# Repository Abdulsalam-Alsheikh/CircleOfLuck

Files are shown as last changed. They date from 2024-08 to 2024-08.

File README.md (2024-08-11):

# Random Number Selector with 12 Segments

This project is an electronic circuit that randomly selects a winner from 12 participants by lighting up the corresponding segment on a circular board. The circuit is built using an Arduino Nano, shift registers, MOSFET transistors, and other components. The design includes a PCB layout, simulation in Proteus, and Arduino code for the logic control.

## Components

- **Arduino Nano**: Controls the entire circuit.
- **2 x 74HC595 Shift Registers**: Expands the number of outputs to control the 12 segments.
- **12 x IRLZ44N MOSFET Transistors**: Used to switch the LEDs for each segment.
- **Resistors**: Various values to limit current and ensure proper operation of the circuit.
- **Power Supply Jack**: To feed the circuit with the required voltage.
- **Junction Connectors**: For connecting each segment to its corresponding transistor.

## Project Files

- **Proteus Simulation File**: A simulation of the circuit to test the functionality before actual implementation **note**( The Arduino code will not work directly here on the simulation due to the adopted method of generating the random number you must change the method of generating the random number before the simulation ) .
- **Arduino Code**: The code used to control the selection process and light up the segments.
- **PCB Design**: A layout of the PCB ready for manufacturing, including all the components and connections.

## Circuit Design

The circuit is designed to randomly select a number from 1 to 12 using an LED on a circular board. The selection is controlled by an Arduino Nano, which sends signals to the shift registers. The shift registers then control the MOSFET transistors, which switch the LEDs on and off based on the random selection.

### How It Works

1. The Arduino generates a random number between 1 and 12.
2. The shift registers receive the number and activate the corresponding MOSFET.
3. The MOSFET then allows current to pass through and lights up the LED corresponding to the selected number.
4. The number remains lit until the process is repeated.

## Usage

1. Load the provided Arduino code into the Arduino Nano.
2. Connect the circuit components as per the schematic in the Proteus file or PCB design.
3. Power the circuit through the power supply jack.
4. The circuit will randomly select a number and light up the corresponding segment.

Watch the final circuit project here [Circuit of CircleOfLuck](https://youtu.be/4vKIFw7FxGo) .
Watch how the circuit logic works here [Logic of CircleOfLuck](https://youtu.be/dwda4XJ68b8) .



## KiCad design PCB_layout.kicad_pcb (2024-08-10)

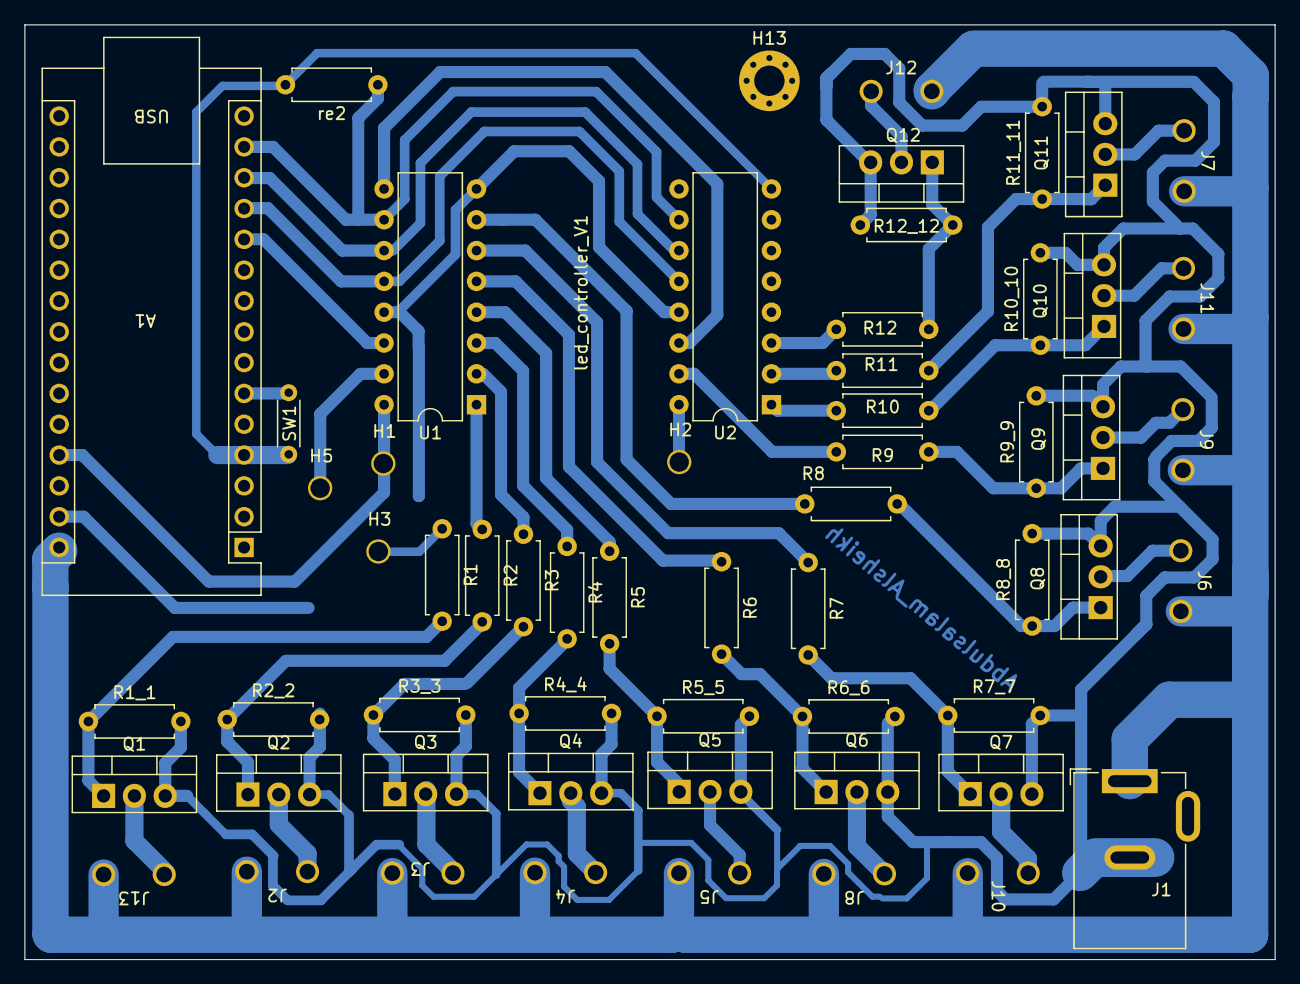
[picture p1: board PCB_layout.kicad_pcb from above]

Board: 2 copper layers, 103.1 x 77.0 mm, 59 parts (0 on the bottom side), 45 nets.

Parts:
A1: Arduino_Nano_v3.x; arduino_nano_abd
H1, H2, H3, H5: MountingHole; abd_foot
H13: MountingHole_Pad; MountingHole_2.5mm_Pad_Via
J1: Barrel_Jack_Switch_Pin3Ring; barreljack_10A
J2, J3, J4, J5, J6, J7, J8, J9, J10, J11, J12, J13: Screw_Terminal_01x02; connector borne
Q1, Q2, Q3, Q4, Q5, Q6, Q7, Q8, Q9, Q10, Q11, Q12: IRLZ44N; TO-220-3_Vertical
R1, R2, R3, R4, R5, R6, R7, R8, R9, R10, R11, R12: 220R; R_Axial_DIN0207_L6.3mm_D2.5mm_P7.62mm_Horizontal
R1_1, R2_2, R3_3, R4_4, R5_5, R6_6, R7_7, R8_8, R9_9, R10_10, R11_11, R12_12: 100k; R_Axial_DIN0207_L6.3mm_D2.5mm_P7.62mm_Horizontal
SW1: SW_DIP_x01; R_Axial_DIN0204_L3.6mm_D1.6mm_P5.08mm_Horizontal
U1, U2: 74HC595; DIP-16_W7.62mm
re2: 100k; R_Axial_DIN0207_L6.3mm_D2.5mm_P7.62mm_Horizontal

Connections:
/1: R1.1, U1.15 (QA)
/2: R2.1, U1.1 (QB)
/3: R3.1, U1.2 (QC)
/4: R4.1, U1.3 (QD)
/5: R5.1, U1.4 (QE)
/6: R6.1, U1.5 (QF)
/7: R7.1, U1.6 (QG)
/8: R8.1, U1.7 (QH)
/9: R9.1, U2.15 (QA)
/10: R10.1, U2.1 (QB)
/11: R11.1, U2.2 (QC)
/12: R12.1, U2.3 (QD)
/+12V: A1.30 (VIN), J1.1, J2.1, J3.1, J4.1, J5.1, J6.1, J7.1, J8.1, J9.1, J10.1, J11.1, J12.1, J13.1
/gnd1: A1.4 (GND), A1.29 (GND), J1.2, Q1.3 (S), Q2.3 (S), Q3.3 (S), Q4.3 (S), Q5.3 (S), Q6.3 (S), Q7.3 (S), Q8.3 (S), Q9.3 (S), Q10.3 (S), Q11.3 (S), Q12.3 (S), R1_1.2, R2_2.2, R3_3.2, R4_4.2, R5_5.2, R6_6.2, R7_7.2, R8_8.2, R9_9.2, R10_10.2, R11_11.2, R12_12.2, SW1.1, U1.8 (GND), U1.13 (~OE), U2.8 (GND), U2.13 (~OE), re2.2
/swich: A1.6 (D3), SW1.2
unnamed: A1.11 (D8), U1.14 (SER)
unnamed: A1.12 (D9), U1.12 (RCLK), U2.12 (RCLK)
unnamed: A1.13 (D10), U1.11 (SRCLK), U2.11 (SRCLK)
unnamed: A1.14 (D11), U1.10 (~SRCLR), U2.10 (~SRCLR), re2.1
unnamed: A1.27 (+5V), U1.16 (VCC), U2.16 (VCC)
unnamed: J2.2, Q2.2 (D)
unnamed: J3.2, Q3.2 (D)
unnamed: J4.2, Q4.2 (D)
unnamed: J5.2, Q5.2 (D)
unnamed: J6.2, Q8.2 (D)
unnamed: J7.2, Q11.2 (D)
unnamed: J8.2, Q6.2 (D)
unnamed: J9.2, Q9.2 (D)
unnamed: J10.2, Q7.2 (D)
unnamed: J11.2, Q10.2 (D)
unnamed: J12.2, Q12.2 (D)
unnamed: J13.2, Q1.2 (D)
unnamed: Q1.1 (G), R1.2, R1_1.1
unnamed: Q2.1 (G), R2.2, R2_2.1
unnamed: Q3.1 (G), R3.2, R3_3.1
unnamed: Q4.1 (G), R4.2, R4_4.1
unnamed: Q5.1 (G), R5.2, R5_5.1
unnamed: Q6.1 (G), R6.2, R6_6.1
unnamed: Q7.1 (G), R7.2, R7_7.1
unnamed: Q8.1 (G), R8.2, R8_8.1
unnamed: Q9.1 (G), R9.2, R9_9.1
unnamed: Q10.1 (G), R10.2, R10_10.1
unnamed: Q11.1 (G), R11.2, R11_11.1
unnamed: Q12.1 (G), R12.2, R12_12.1
unnamed: U1.9 (QH'), U2.14 (SER)

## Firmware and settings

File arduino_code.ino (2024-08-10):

#define clockPin 10 // Clock pin of 74HC595 is connected to Digital pin 10
#define dataPin  9  // Data  pin of 74HC595 is connected to Digital pin 9 
#define latchPin 8  // Latch pin of 74HC595 is connected to Digital pin 8
#define clr 7

int win_arr[12];
void setup() {
  Serial.begin(9600);
  pinMode(3, INPUT_PULLUP);
  pinMode(latchPin, OUTPUT);
  pinMode(clockPin, OUTPUT);
  pinMode(dataPin, OUTPUT);
  pinMode(clr, OUTPUT);

  digitalWrite(clr, HIGH);

  led_diplay_start_finish_forward();


}

void loop() {
  int t = 0;
  for (int i = 0; i < 12; i++) {
    if (win_arr[i] == 1) {
      t++;
    }
  }
  Serial.println(digitalRead(3));
  if (digitalRead(3) == LOW || t == 12) {
    start_finish_control();
    // generate a random value for loop
    int A0_loop = analogRead(A0);
    int ran_loop = A0_loop % 2 + 3;
    // generate a random winer
    int A0_winer = analogRead(A0);
    int winer = A0_winer % 12 + 1;
    //for every click on buttom chose a difernent winer
    while (win_arr[winer - 1] == 1) {
      A0_winer = analogRead(A0);
      winer = A0_winer % 12 + 1;
    }
    win_arr[winer - 1] = 1;
    winer = winer + 12 * (ran_loop - 1);

    //loop that is decide how much led move before stop in one of 12 led
    for (int j = 0; j < ran_loop; j++) {
      int iter = 0;
      if (winer >= 12) {
        iter = 12;
        winer -= 12;
      }
      else {
        iter = winer;
      }

      for (long int i = 1; i < int(pow(2, iter)); i *= 2) {

        digitalWrite(latchPin, LOW);
        if (i < 256) {
          shiftOut(dataPin, clockPin, MSBFIRST, 0 );
          shiftOut(dataPin, clockPin, MSBFIRST, i );
        }
        else {
          shiftOut(dataPin, clockPin, MSBFIRST, i / 256);
          shiftOut(dataPin, clockPin, MSBFIRST, 0);
        }
        digitalWrite(latchPin, HIGH);
        delay(100);
      }
      //for blink led after stop
      if (iter < 12 || (iter==12 && winer==0)) {
        long int sum_blink = 1;
        int bli_iter = iter - 1;
        for(int f=0; f<bli_iter ;f++){
            sum_blink*=2;
          }
        for (int k = 0; k < 3; k++) {
          delay(400);
          digitalWrite(latchPin, LOW);
          shiftOut(dataPin, clockPin, MSBFIRST, 0 );
          shiftOut(dataPin, clockPin, MSBFIRST, 0 );
          digitalWrite(latchPin, HIGH);
          delay(400);
          
          digitalWrite(latchPin, LOW);
          if (iter <= 8) {
            shiftOut(dataPin, clockPin, MSBFIRST, 0 );
            shiftOut(dataPin, clockPin, MSBFIRST, sum_blink);
          }
          else {
            shiftOut(dataPin, clockPin, MSBFIRST, sum_blink / 256 );
            shiftOut(dataPin, clockPin, MSBFIRST, 0);
          }
          digitalWrite(latchPin, HIGH);
        }
      }



    }
  }
}

void led_diplay_start_finish_forward() {

  int sum_first = 0;
  int sum_second = 0;
  for (long int i = 1; i < int(pow(2, 12)); i *= 2) {
    digitalWrite(latchPin, LOW);

    if (i < 256) {
      sum_first += i;
      shiftOut(dataPin, clockPin, MSBFIRST, 0 );
      shiftOut(dataPin, clockPin, MSBFIRST, sum_first);
    }
    else {
      sum_second += i / 256;
      shiftOut(dataPin, clockPin, MSBFIRST, sum_second);
      shiftOut(dataPin, clockPin, MSBFIRST, sum_first);
    }
    digitalWrite(latchPin, HIGH);
    delay(500);
  }
}

void led_diplay_start_again_back() {

  int sum_first = 0;
  int sum_second = 0;
  for (long int i = int(pow(2, 11)); i >= 1; i /= 2) {
    digitalWrite(latchPin, LOW);

    if (i < 256) {
      sum_first += i;
      shiftOut(dataPin, clockPin, MSBFIRST, sum_second );
      shiftOut(dataPin, clockPin, MSBFIRST, sum_first);
    }
    else {
      sum_second += i / 256;
      shiftOut(dataPin, clockPin, MSBFIRST, sum_second);
      shiftOut(dataPin, clockPin, MSBFIRST, sum_first);
    }
    digitalWrite(latchPin, HIGH);
    delay(500);
  }
}

void start_finish_control() {
  int n = 0;
  for (int i = 0; i < 12; i++) {
    if (win_arr[i] == 1) {
      n++;
    }
  }
  int ones = 0;
  while (n == 12) {
    if (ones == 0) {
      delay(4000);
      led_diplay_start_finish_forward();
      ones = 1;
    }
    if (digitalRead(3) == LOW) {
      led_diplay_start_again_back();
      n = 0;
      for (int i = 0; i < 12; i++) {
        win_arr[i] = 0;
      }
    }
  }
}

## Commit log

2024-08-13 Update and rename led-controller.kicad_sch to schematic diagram.kicad_sch
    [schematic diagram.kicad_sch]
2024-08-13 Update and rename led-controller.kicad_pcb to PCB layout.kicad_pcb
    [PCB layout.kicad_pcb]
2024-08-13 Update and rename schematic diagram.kicad_sch to schematic_diagram.kicad_sch
    [schematic_diagram.kicad_sch]
2024-08-13 Update and rename PCB layout.kicad_pcb to PCB_layout.kicad_pcb
    [PCB_layout.kicad_pcb]
